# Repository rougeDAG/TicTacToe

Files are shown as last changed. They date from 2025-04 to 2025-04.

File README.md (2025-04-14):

<h1>TicTacToe</h1>

A first year graded project I submitted for my course in Digital System Design (Winter Semester, Vellore Institue of Technology, Chennai). This is a Tic Tac Toe game that uses only digital logic to play the game. PCB Design was done on KiCad , an open source PCB Design software. I simulated the circuit in another open source digital simulator called Digital.exe (which is based on another software called Logisim) by Helmut Neemann which I downloaded from his GitHub repository.
Digital.exe helped me immensely in my project as I cannot have simulated my project without this software for free. Here is his GitHub repository: [github.com/hneemann/Digital](#github.com/hneemann/Digital)


_________________________________________________________________________________________________________________________________________________________________________________________________________________________________________________

Now for KiCad, I used another free and open source software called Freerouting by Andras Fuchs to auto-route my wire connections in KiCad. Here is that GitHub repository: [github.com/freerouting/freerouting](#github.com/freerouting/freerouting)

Again it would've been painstaking to connect all the components pinouts invidivually , thus this software also played a massive role in saving time as I had to submit my project in a short span of time.

 To open the files in KiCad, go to KiCad, click on File->Open Project and then open the file folder thats downloaded and click on "DSD_Project" of the file type "KiCad Project 9.0". Updated versions may come in the future but it still should work the same.

 To open the files in Digital.exe, go to Digital, click on Open and click on "dsd_project_digital.dig".

_________________________________________________________________________________________________________________________________________________________________________________________________________________________________________________

<h1>Sneek Peek into Digital.exe simulation:</h1>






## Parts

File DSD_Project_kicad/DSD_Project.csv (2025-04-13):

Reference | Qty | Value | DNP | Exclude from BOM | Exclude from Board | Footprint | Datasheet | Description | #
button1,button2,button3,button4,button5,button6,button7,button8,button9,D_Clear1,D_Preset1 | 11 | SW_Push |  |  |  |  | ~ | Push button switch, generic, two pins | 1
U1,U6,U8 | 3 | 74LS02 |  |  |  |  | http://www.ti.com/lit/gpn/sn74ls02 | quad 2-input NOR gate | 2
U2,U9,U10,U12,U13,U14 | 6 | 74LS11 |  |  |  |  | http://www.ti.com/lit/gpn/sn74LS11 | Triple 3-input AND | 3
U3,U5,U7 | 3 | 74LS08 |  |  |  |  | http://www.ti.com/lit/gpn/sn74LS08 | Quad And2 | 4
U4,U11 | 2 | 74LS14 |  |  |  |  | http://www.ti.com/lit/gpn/sn74LS14 | Hex inverter schmitt trigger | 5
U15,U16,U17,U18,U19,U20,U21,U22,U23 | 9 | 74LS74 |  |  |  |  | 74xx/74hc_hct74.pdf | Dual D Flip-flop, Set & Reset | 6

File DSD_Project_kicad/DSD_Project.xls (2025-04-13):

Reference | Qty | Value | DNP | Exclude from BOM | Exclude from Board | Footprint | Datasheet | Description | #
button1,button2,button3,button4,button5,button6,button7,button8,button9,D_Clear?,D_Preset? | 11 | SW_Push |  |  |  |  | ~ | Push button switch, generic, two pins | 1
U1,U11,U13,U15,U20,U21,U24,U26,U28 | 9 | 74LS74 |  |  |  |  | 74xx/74hc_hct74.pdf | Dual D Flip-flop, Set & Reset | 2
U2,U18,U27 | 3 | 74LS02 |  |  |  |  | http://www.ti.com/lit/gpn/sn74ls02 | quad 2-input NOR gate | 3
U3,U5,U17 | 3 | 74LS08 |  |  |  |  | http://www.ti.com/lit/gpn/sn74LS08 | Quad And2 | 4
U4,U8,U9,U19,U22,U25 | 6 | 74LS11 |  |  |  |  | http://www.ti.com/lit/gpn/sn74LS11 | Triple 3-input AND | 5
U6,U23 | 2 | 74LS14 |  |  |  |  | http://www.ti.com/lit/gpn/sn74LS14 | Hex inverter schmitt trigger | 6

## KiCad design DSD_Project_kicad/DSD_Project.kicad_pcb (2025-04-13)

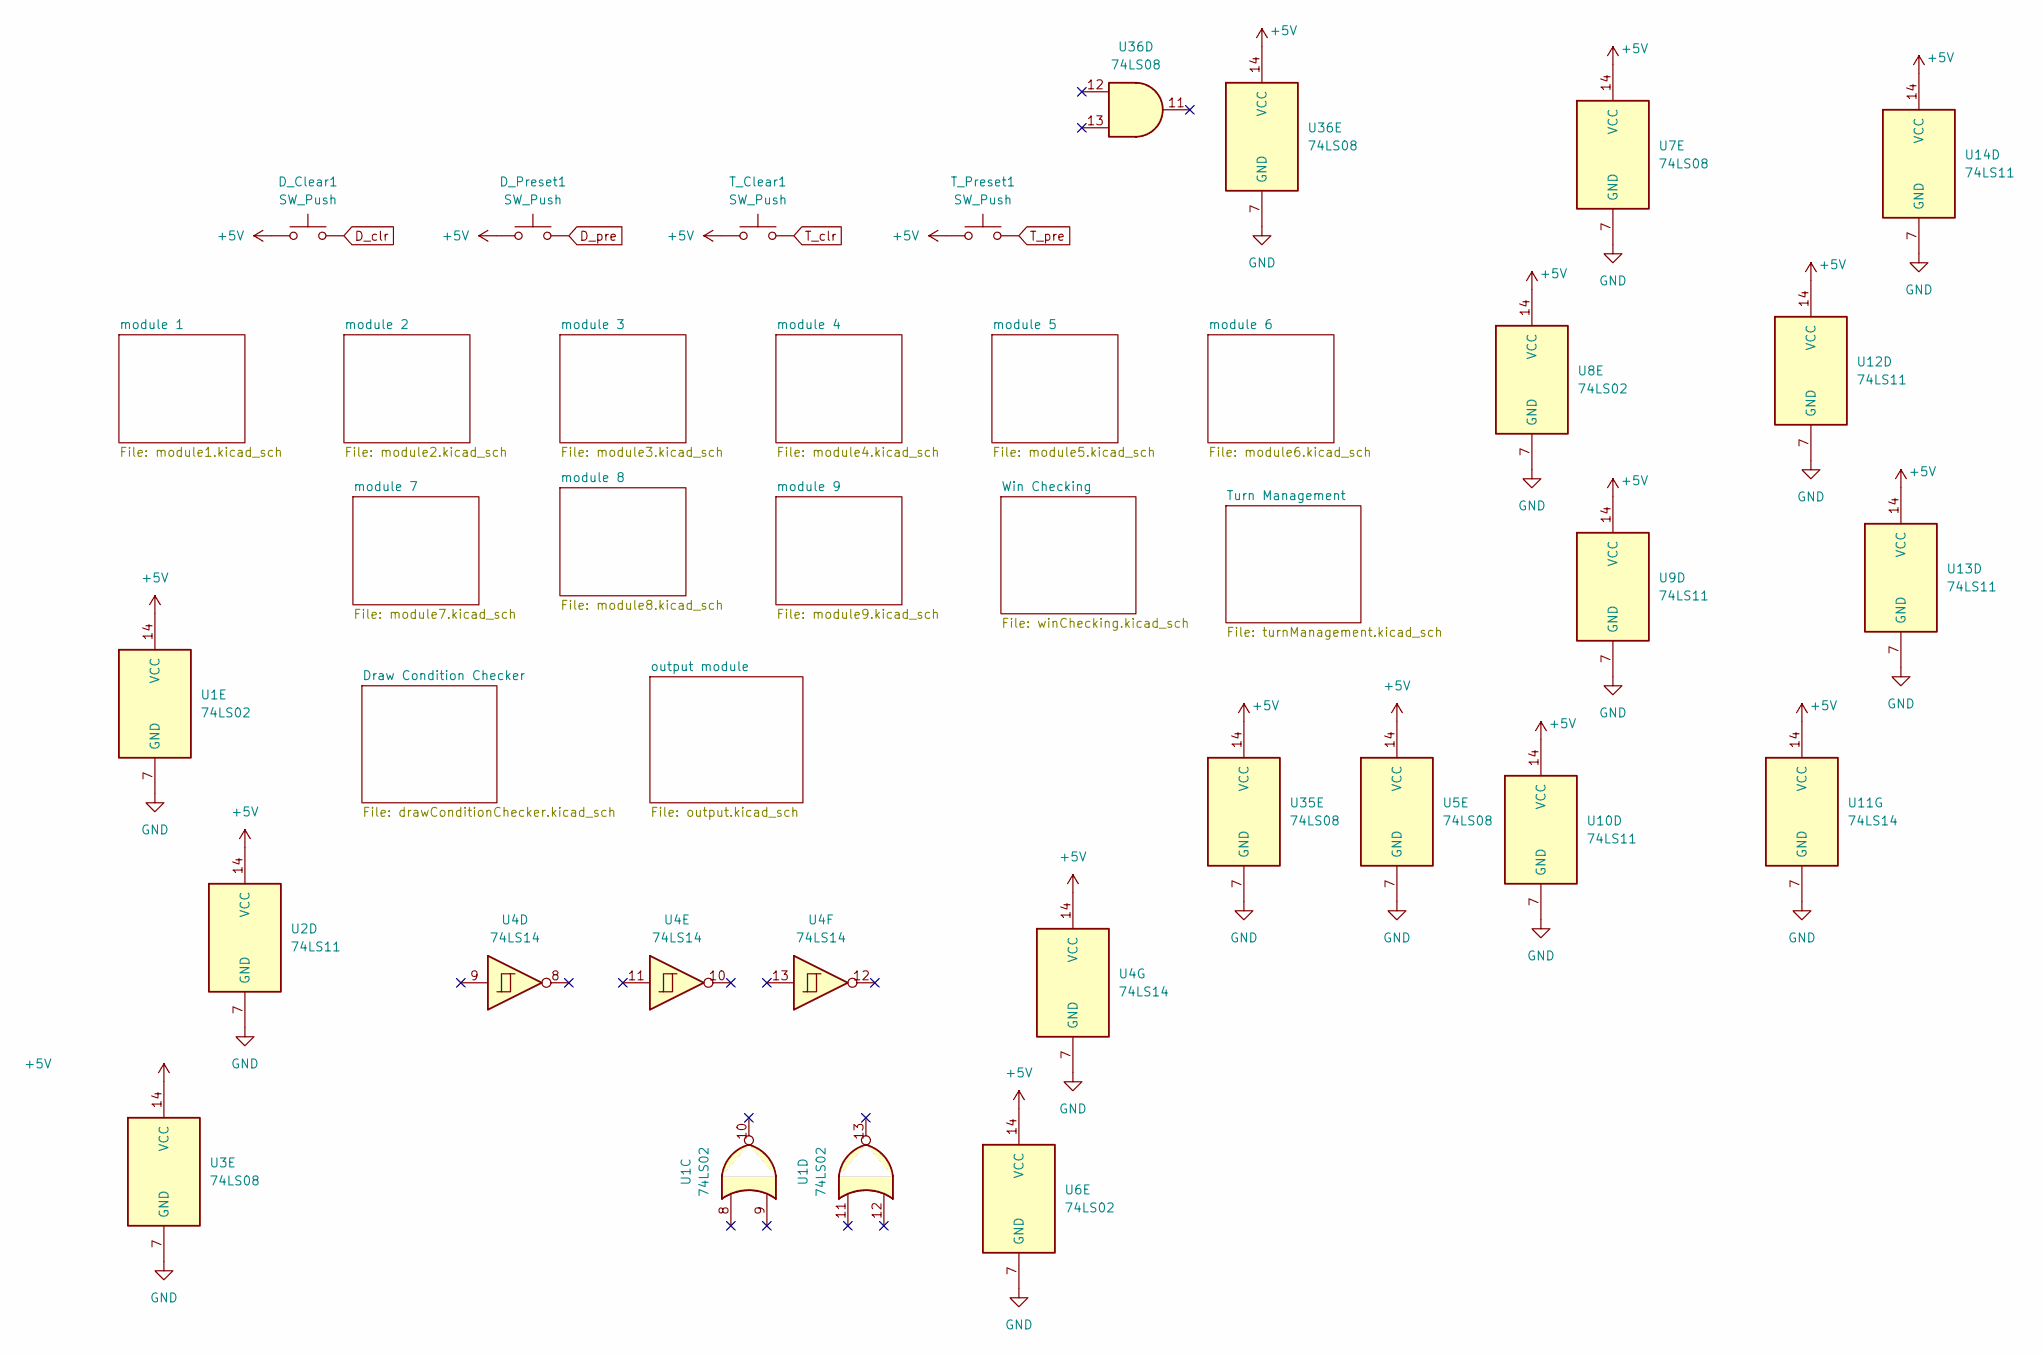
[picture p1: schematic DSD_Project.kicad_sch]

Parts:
D_Clear1: SW_Push; SW_SPDT_PCM12
D_Preset1: SW_Push; SW_SPDT_PCM12
T_Clear1: SW_Push; SW_SPDT_PCM12
T_Preset1: SW_Push; SW_SPDT_PCM12
U1, U6, U8: 74LS02; DIP-14_W7.62mm
U2, U9, U10, U12, U13, U14: 74LS11; DIP-14_W7.62mm
U3, U5, U7, U35, U36: 74LS08; DIP-14_W7.62mm
U4, U11: 74LS14; DIP-14_W7.62mm

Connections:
+5V: D_Clear1.1, D_Preset1.1, T_Clear1.1, T_Preset1.1, U1.14 (VCC), U2.14 (VCC), U3.14 (VCC), U4.14 (VCC), U5.14 (VCC), U6.14 (VCC), U7.14 (VCC), U8.14 (VCC), U9.14 (VCC), U10.14 (VCC), U11.14 (VCC), U12.14 (VCC), U13.14 (VCC), U14.14 (VCC), U35.14 (VCC), U36.14 (VCC); also elsewhere on the board
D_clr: D_Clear1.2; also elsewhere on the board
D_pre: D_Preset1.2; also elsewhere on the board
GND: U1.7 (GND), U2.7 (GND), U3.7 (GND), U4.7 (GND), U5.7 (GND), U6.7 (GND), U7.7 (GND), U8.7 (GND), U9.7 (GND), U10.7 (GND), U11.7 (GND), U12.7 (GND), U13.7 (GND), U14.7 (GND), U35.7 (GND), U36.7 (GND); also elsewhere on the board
T_clr: T_Clear1.2; also elsewhere on the board
T_pre: T_Preset1.2; also elsewhere on the board

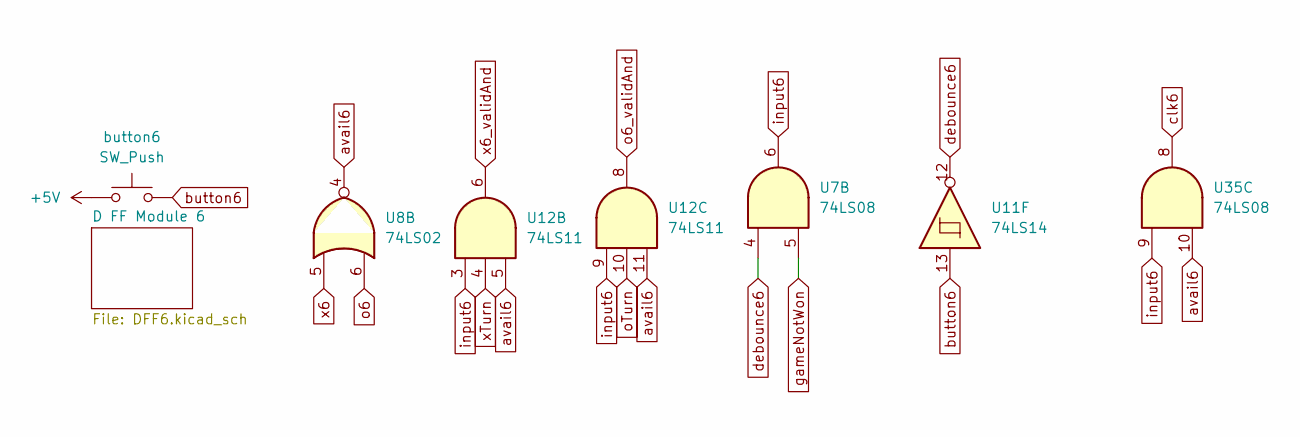
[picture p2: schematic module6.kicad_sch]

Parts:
U7, U35: 74LS08; DIP-14_W7.62mm
U8: 74LS02; DIP-14_W7.62mm
U11: 74LS14; DIP-14_W7.62mm
U12: 74LS11; DIP-14_W7.62mm
button6: SW_Push; SW_PUSH_6mm

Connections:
+5V: button6.1; also elsewhere on the board
avail6: U8.4, U12.5, U12.11, U35.10; also elsewhere on the board
button6: U11.13, button6.2
clk6: U35.8; also elsewhere on the board
debounce6: U7.4, U11.12
gameNotWon: U7.5; also elsewhere on the board
input6: U7.6, U12.3, U12.9, U35.9
o6: U8.6; also elsewhere on the board
o6_validAnd: U12.8; also elsewhere on the board
oTurn: U12.10; also elsewhere on the board
x6: U8.5; also elsewhere on the board
x6_validAnd: U12.6; also elsewhere on the board
xTurn: U12.4; also elsewhere on the board

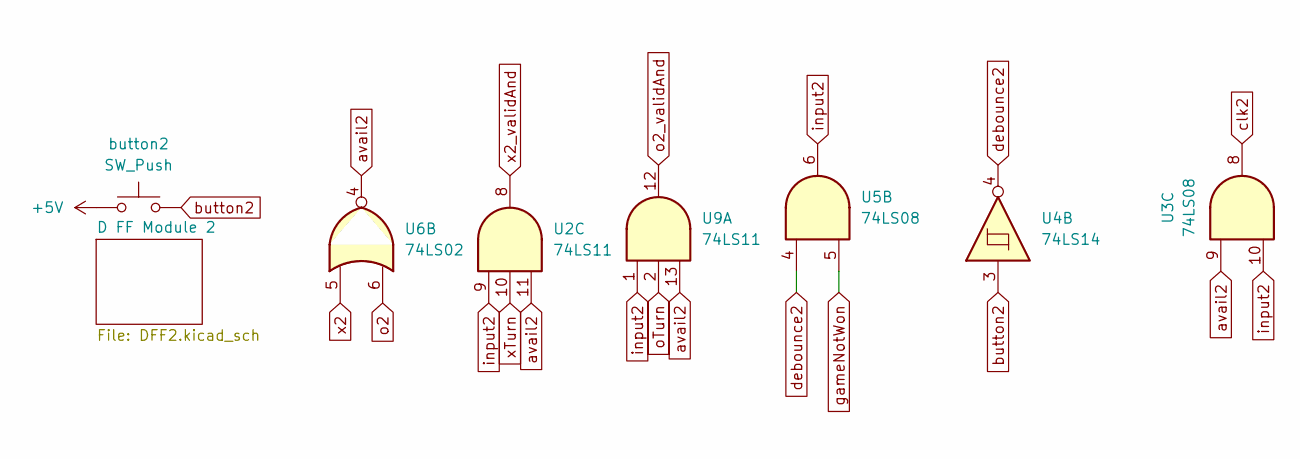
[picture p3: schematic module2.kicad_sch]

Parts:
U2, U9: 74LS11; DIP-14_W7.62mm
U3, U5: 74LS08; DIP-14_W7.62mm
U4: 74LS14; DIP-14_W7.62mm
U6: 74LS02; DIP-14_W7.62mm
button2: SW_Push; SW_PUSH_6mm

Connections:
+5V: button2.1; also elsewhere on the board
avail2: U2.11, U3.9, U6.4, U9.13; also elsewhere on the board
button2: U4.3, button2.2
clk2: U3.8; also elsewhere on the board
debounce2: U4.4, U5.4
gameNotWon: U5.5; also elsewhere on the board
input2: U2.9, U3.10, U5.6, U9.1
o2: U6.6; also elsewhere on the board
o2_validAnd: U9.12; also elsewhere on the board
oTurn: U9.2; also elsewhere on the board
x2: U6.5; also elsewhere on the board
x2_validAnd: U2.8; also elsewhere on the board
xTurn: U2.10; also elsewhere on the board

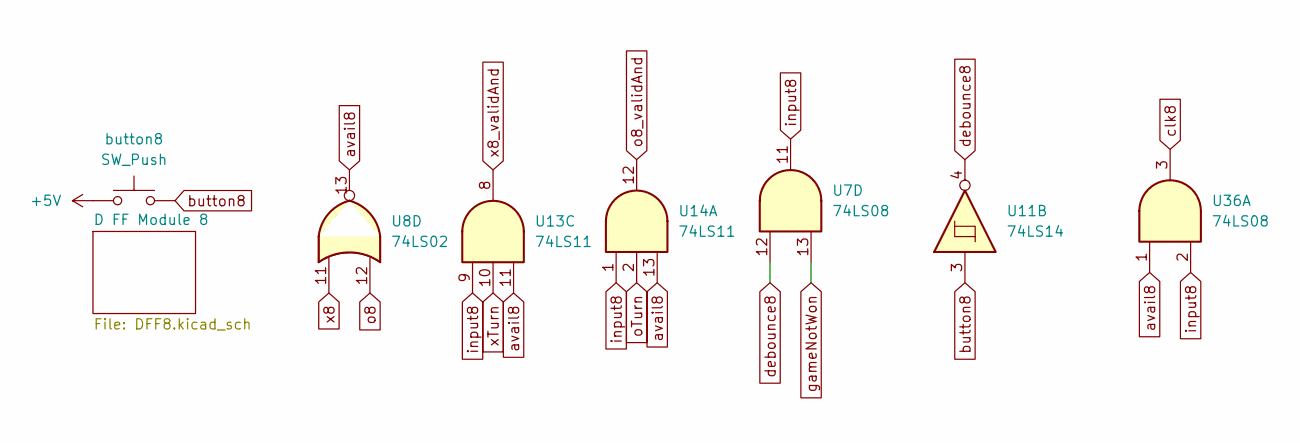
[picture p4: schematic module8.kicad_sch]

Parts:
U7, U36: 74LS08; DIP-14_W7.62mm
U8: 74LS02; DIP-14_W7.62mm
U11: 74LS14; DIP-14_W7.62mm
U13, U14: 74LS11; DIP-14_W7.62mm
button8: SW_Push; SW_PUSH_6mm

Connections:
+5V: button8.1; also elsewhere on the board
avail8: U8.13, U13.11, U14.13, U36.1; also elsewhere on the board
button8: U11.3, button8.2
clk8: U36.3; also elsewhere on the board
debounce8: U7.12, U11.4
gameNotWon: U7.13; also elsewhere on the board
input8: U7.11, U13.9, U14.1, U36.2
o8: U8.12; also elsewhere on the board
o8_validAnd: U14.12; also elsewhere on the board
oTurn: U14.2; also elsewhere on the board
x8: U8.11; also elsewhere on the board
x8_validAnd: U13.8; also elsewhere on the board
xTurn: U13.10; also elsewhere on the board

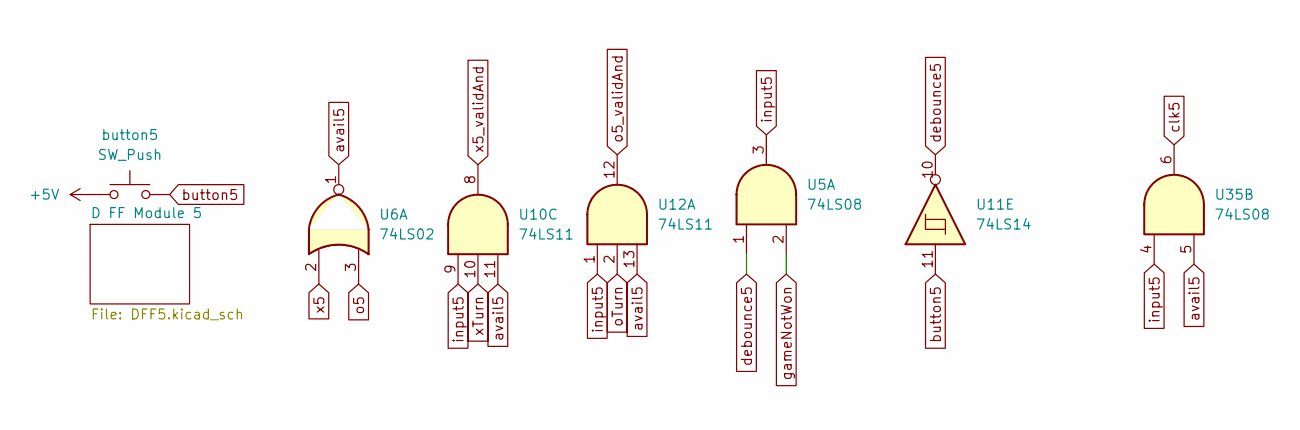
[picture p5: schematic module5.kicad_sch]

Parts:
U5, U35: 74LS08; DIP-14_W7.62mm
U6: 74LS02; DIP-14_W7.62mm
U10, U12: 74LS11; DIP-14_W7.62mm
U11: 74LS14; DIP-14_W7.62mm
button5: SW_Push; SW_PUSH_6mm

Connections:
+5V: button5.1; also elsewhere on the board
avail5: U6.1, U10.11, U12.13, U35.5; also elsewhere on the board
button5: U11.11, button5.2
clk5: U35.6; also elsewhere on the board
debounce5: U5.1, U11.10
gameNotWon: U5.2; also elsewhere on the board
input5: U5.3, U10.9, U12.1, U35.4
o5: U6.3; also elsewhere on the board
o5_validAnd: U12.12; also elsewhere on the board
oTurn: U12.2; also elsewhere on the board
x5: U6.2; also elsewhere on the board
x5_validAnd: U10.8; also elsewhere on the board
xTurn: U10.10; also elsewhere on the board

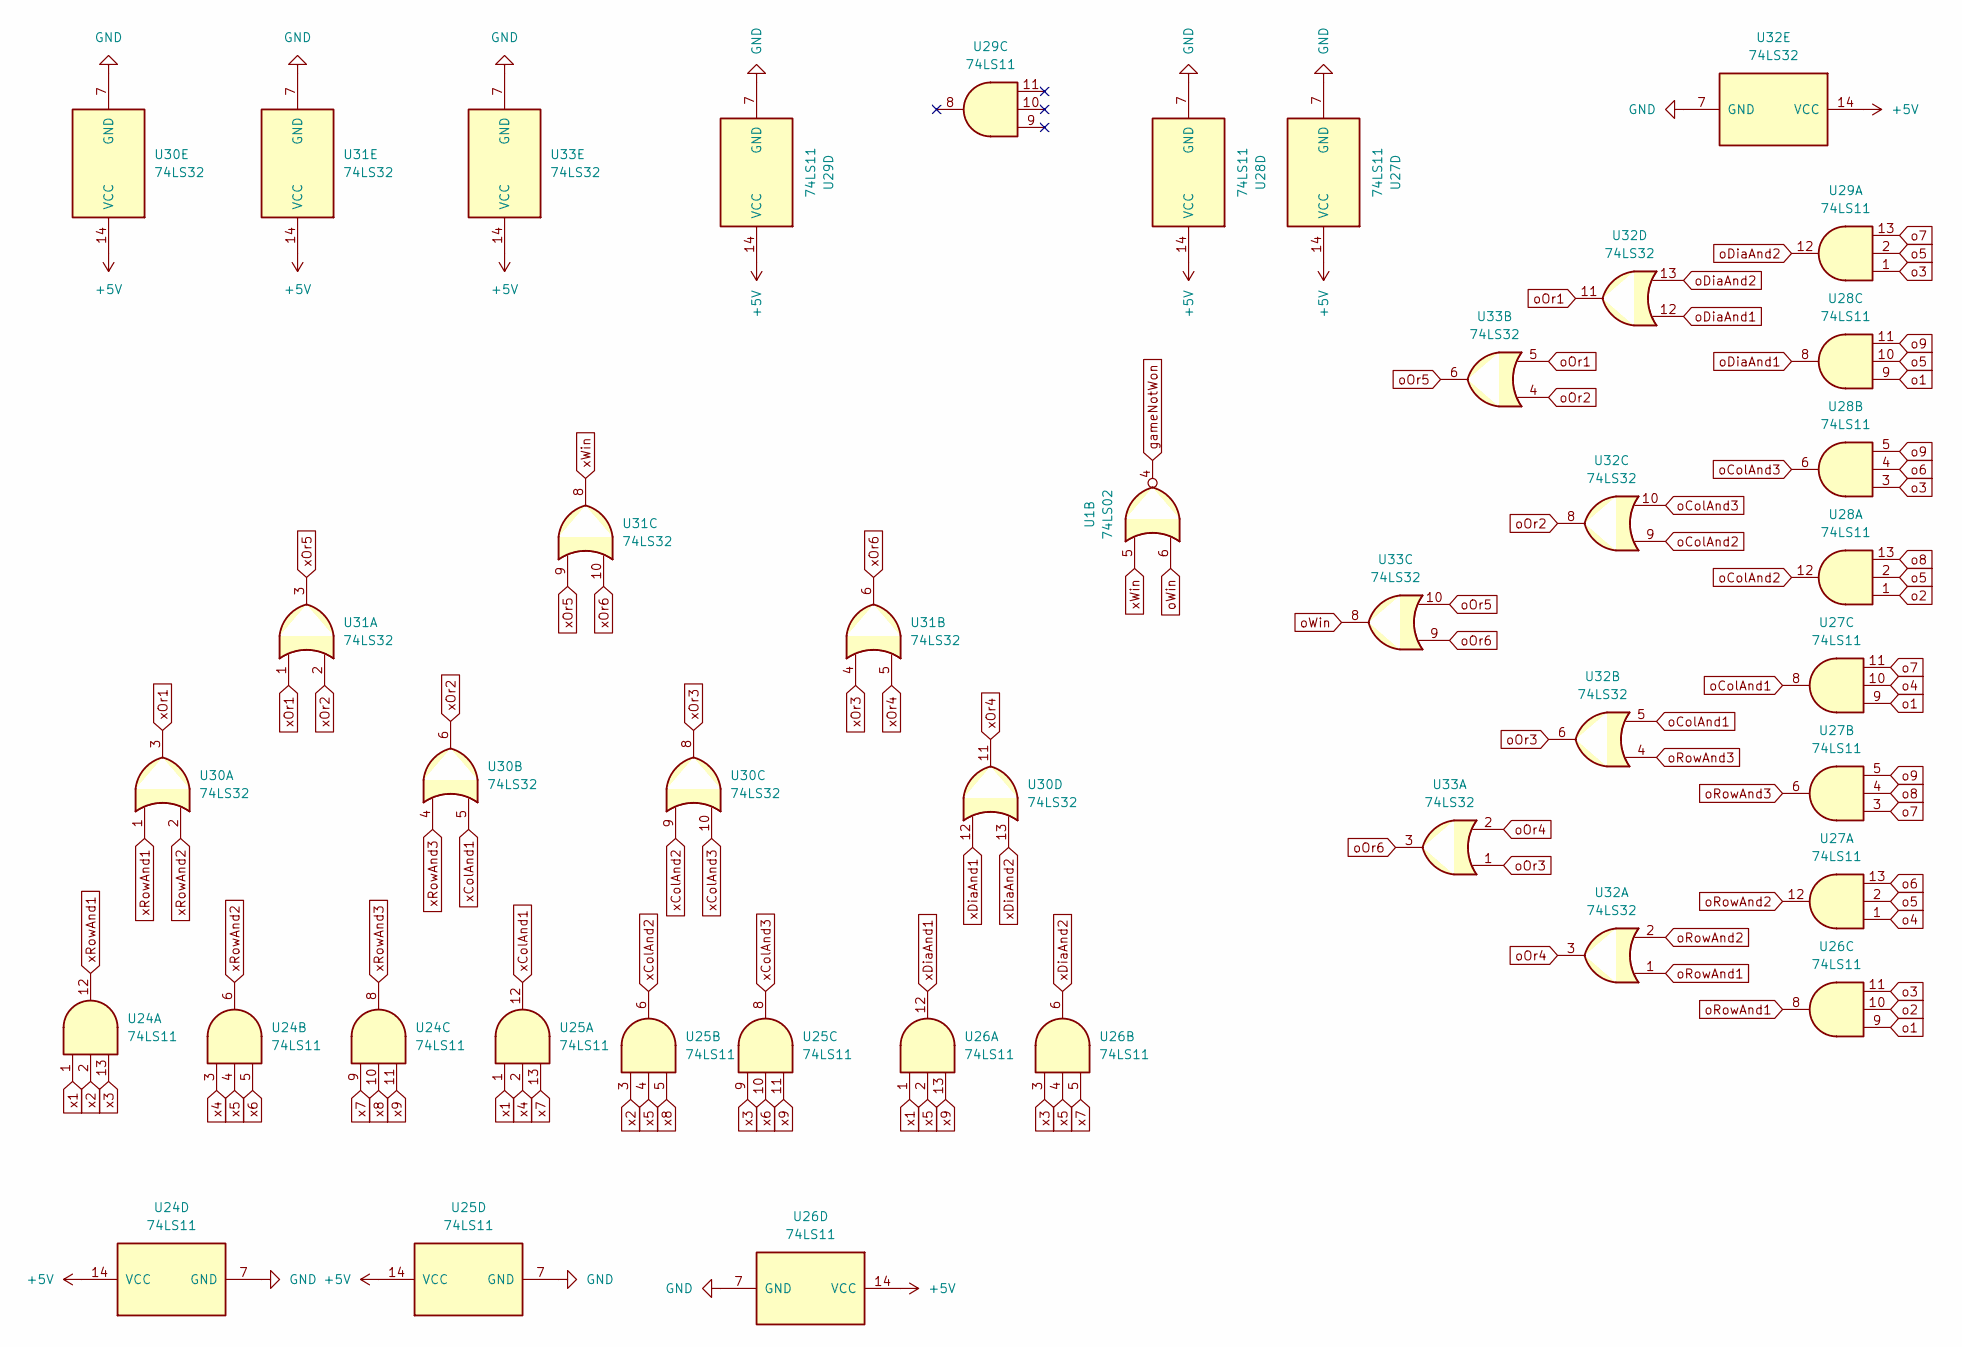
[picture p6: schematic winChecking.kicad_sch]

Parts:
U1: 74LS02; DIP-14_W7.62mm
U24, U25, U26, U27, U28, U29: 74LS11; DIP-14_W7.62mm
U30, U31, U32, U33: 74LS32; DIP-14_W7.62mm

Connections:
+5V: U24.14 (VCC), U25.14 (VCC), U26.14 (VCC), U27.14 (VCC), U28.14 (VCC), U29.14 (VCC), U30.14 (VCC), U31.14 (VCC), U32.14 (VCC), U33.14 (VCC); also elsewhere on the board
GND: U24.7 (GND), U25.7 (GND), U26.7 (GND), U27.7 (GND), U28.7 (GND), U29.7 (GND), U30.7 (GND), U31.7 (GND), U32.7 (GND), U33.7 (GND); also elsewhere on the board
gameNotWon: U1.4; also elsewhere on the board
o1: U26.9, U27.9, U28.9; also elsewhere on the board
o2: U26.10, U28.1; also elsewhere on the board
o3: U26.11, U28.3, U29.1; also elsewhere on the board
o4: U27.1, U27.10; also elsewhere on the board
o5: U27.2, U28.2, U28.10, U29.2; also elsewhere on the board
o6: U27.13, U28.4; also elsewhere on the board
o7: U27.3, U27.11, U29.13; also elsewhere on the board
o8: U27.4, U28.13; also elsewhere on the board
o9: U27.5, U28.5, U28.11; also elsewhere on the board
oColAnd1: U27.8, U32.5
oColAnd2: U28.12, U32.9
oColAnd3: U28.6, U32.10
oDiaAnd1: U28.8, U32.12
oDiaAnd2: U29.12, U32.13
oOr1: U32.11, U33.5
oOr2: U32.8, U33.4
oOr3: U32.6, U33.1
oOr4: U32.3, U33.2
oOr5: U33.6, U33.10
oOr6: U33.3, U33.9
oRowAnd1: U26.8, U32.1
oRowAnd2: U27.12, U32.2
oRowAnd3: U27.6, U32.4
oWin: U1.6, U33.8; also elsewhere on the board
x1: U24.1, U25.1, U26.1; also elsewhere on the board
x2: U24.2, U25.3; also elsewhere on the board
x3: U24.13, U25.9, U26.3; also elsewhere on the board
x4: U24.3, U25.2; also elsewhere on the board
x5: U24.4, U25.4, U26.2, U26.4; also elsewhere on the board
x6: U24.5, U25.10; also elsewhere on the board
x7: U24.9, U25.13, U26.5; also elsewhere on the board
x8: U24.10, U25.5; also elsewhere on the board
x9: U24.11, U25.11, U26.13; also elsewhere on the board
xColAnd1: U25.12, U30.5
xColAnd2: U25.6, U30.9
xColAnd3: U25.8, U30.10
xDiaAnd1: U26.12, U30.12
xDiaAnd2: U26.6, U30.13
xOr1: U30.3, U31.1
xOr2: U30.6, U31.2
xOr3: U30.8, U31.4
xOr4: U30.11, U31.5
xOr5: U31.3, U31.9
xOr6: U31.6, U31.10
xRowAnd1: U24.12, U30.1
xRowAnd2: U24.6, U30.2
xRowAnd3: U24.8, U30.4
xWin: U1.5, U31.8; also elsewhere on the board

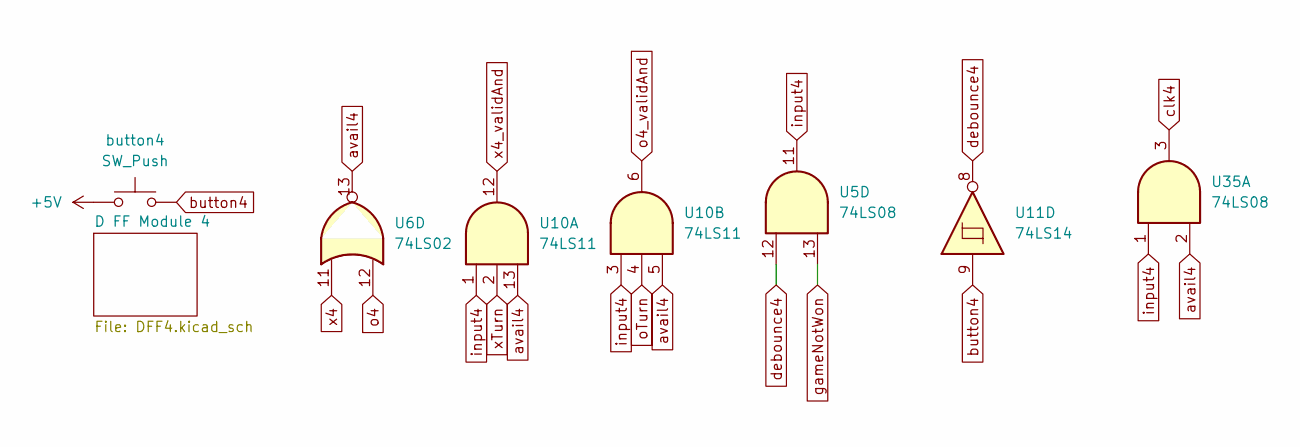
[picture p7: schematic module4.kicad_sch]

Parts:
U5, U35: 74LS08; DIP-14_W7.62mm
U6: 74LS02; DIP-14_W7.62mm
U10: 74LS11; DIP-14_W7.62mm
U11: 74LS14; DIP-14_W7.62mm
button4: SW_Push; SW_PUSH_6mm

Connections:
+5V: button4.1; also elsewhere on the board
avail4: U6.13, U10.5, U10.13, U35.2; also elsewhere on the board
button4: U11.9, button4.2
clk4: U35.3; also elsewhere on the board
debounce4: U5.12, U11.8
gameNotWon: U5.13; also elsewhere on the board
input4: U5.11, U10.1, U10.3, U35.1
o4: U6.12; also elsewhere on the board
o4_validAnd: U10.6; also elsewhere on the board
oTurn: U10.4; also elsewhere on the board
x4: U6.11; also elsewhere on the board
x4_validAnd: U10.12; also elsewhere on the board
xTurn: U10.2; also elsewhere on the board

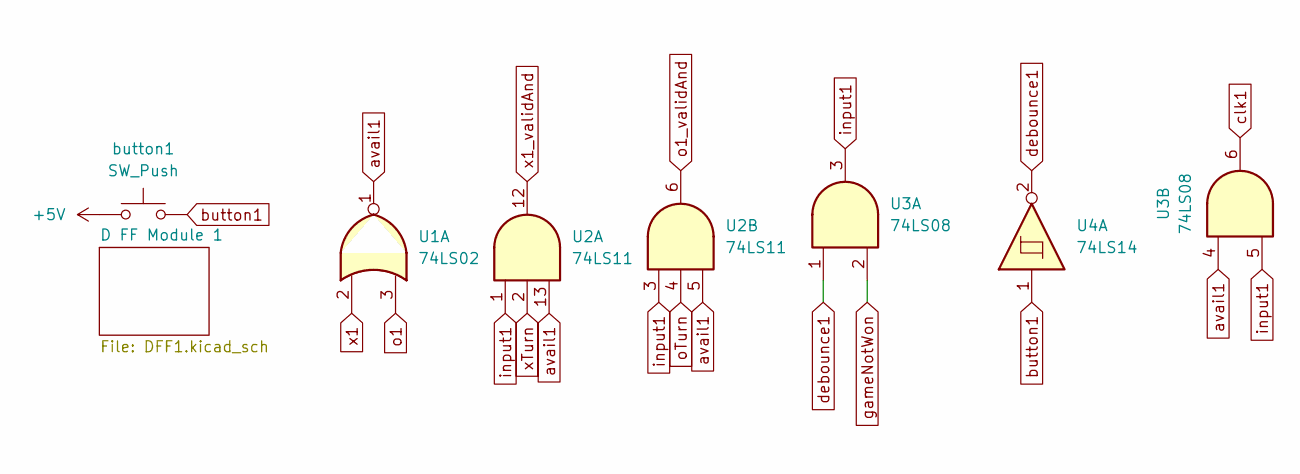
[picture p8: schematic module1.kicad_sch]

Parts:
U1: 74LS02; DIP-14_W7.62mm
U2: 74LS11; DIP-14_W7.62mm
U3: 74LS08; DIP-14_W7.62mm
U4: 74LS14; DIP-14_W7.62mm
button1: SW_Push; SW_PUSH_6mm

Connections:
+5V: button1.1; also elsewhere on the board
avail1: U1.1, U2.5, U2.13, U3.4; also elsewhere on the board
button1: U4.1, button1.2
clk1: U3.6; also elsewhere on the board
debounce1: U3.1, U4.2
gameNotWon: U3.2; also elsewhere on the board
input1: U2.1, U2.3, U3.3, U3.5
o1: U1.3; also elsewhere on the board
o1_validAnd: U2.6; also elsewhere on the board
oTurn: U2.4; also elsewhere on the board
x1: U1.2; also elsewhere on the board
x1_validAnd: U2.12; also elsewhere on the board
xTurn: U2.2; also elsewhere on the board

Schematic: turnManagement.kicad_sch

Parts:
U31, U33, U37, U38: 74LS32; DIP-14_W7.62mm
U34: 74LS76; DIP-16_W7.62mm

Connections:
+5V: U34.4 (J), U34.5 (VCC), U34.16 (K), U37.14 (VCC), U38.14 (VCC); also elsewhere on the board
GND: U34.13 (GND), U37.7 (GND), U38.7 (GND); also elsewhere on the board
T_clr: U34.3 (~R); also elsewhere on the board
T_pre: U34.2 (~S); also elsewhere on the board
clk1: U31.12; also elsewhere on the board
clk2: U31.13; also elsewhere on the board
clk3: U33.12; also elsewhere on the board
clk4: U33.13; also elsewhere on the board
clk5: U37.1; also elsewhere on the board
clk6: U37.2; also elsewhere on the board
clk7: U37.4; also elsewhere on the board
clk8: U37.5; also elsewhere on the board
clk9: U37.10; also elsewhere on the board
clkOr1: U31.11, U38.4
clkOr2: U33.11, U37.12
clkOr3: U37.3, U37.13
clkOr4: U37.6, U37.9
clkOr5: U37.11, U38.1
clkOr6: U37.8, U38.2
clkOr7: U38.3, U38.5
oTurn: U34.14 (~Q); also elsewhere on the board
tclk: U34.1 (C), U38.6
xTurn: U34.15 (Q); also elsewhere on the board

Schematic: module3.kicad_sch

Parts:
U3, U5: 74LS08; DIP-14_W7.62mm
U4: 74LS14; DIP-14_W7.62mm
U6: 74LS02; DIP-14_W7.62mm
U9: 74LS11; DIP-14_W7.62mm
button3: SW_Push; SW_PUSH_6mm

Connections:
+5V: button3.1; also elsewhere on the board
avail3: U3.12, U6.10, U9.5, U9.11; also elsewhere on the board
button3: U4.5, button3.2
clk3: U3.11; also elsewhere on the board
debounce3: U4.6, U5.9
gameNotWon: U5.10; also elsewhere on the board
input3: U3.13, U5.8, U9.3, U9.9
o3: U6.9; also elsewhere on the board
o3_validAnd: U9.8; also elsewhere on the board
oTurn: U9.10; also elsewhere on the board
x3: U6.8; also elsewhere on the board
x3_validAnd: U9.6; also elsewhere on the board
xTurn: U9.4; also elsewhere on the board

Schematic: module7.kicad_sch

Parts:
U7, U35: 74LS08; DIP-14_W7.62mm
U8: 74LS02; DIP-14_W7.62mm
U11: 74LS14; DIP-14_W7.62mm
U13: 74LS11; DIP-14_W7.62mm
button7: SW_Push; SW_PUSH_6mm

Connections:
+5V: button7.1; also elsewhere on the board
avail7: U8.10, U13.5, U13.13, U35.13; also elsewhere on the board
button7: U11.1, button7.2
clk7: U35.11; also elsewhere on the board
debounce7: U7.9, U11.2
gameNotWon: U7.10; also elsewhere on the board
input7: U7.8, U13.1, U13.3, U35.12
o7: U8.9; also elsewhere on the board
o7_validAnd: U13.6; also elsewhere on the board
oTurn: U13.4; also elsewhere on the board
x7: U8.8; also elsewhere on the board
x7_validAnd: U13.12; also elsewhere on the board
xTurn: U13.2; also elsewhere on the board

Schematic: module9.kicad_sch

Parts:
U7, U36: 74LS08; DIP-14_W7.62mm
U8: 74LS02; DIP-14_W7.62mm
U11: 74LS14; DIP-14_W7.62mm
U14: 74LS11; DIP-14_W7.62mm
button9: SW_Push; SW_PUSH_6mm

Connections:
+5V: button9.1; also elsewhere on the board
avail9: U8.1, U14.5, U14.11, U36.5; also elsewhere on the board
button9: U11.5, button9.2
clk9: U36.6; also elsewhere on the board
debounce9: U7.1, U11.6
gameNotWon: U7.2; also elsewhere on the board
input9: U7.3, U14.3, U14.9, U36.4
o9: U8.3; also elsewhere on the board
o9_validAnd: U14.8; also elsewhere on the board
oTurn: U14.10; also elsewhere on the board
x9: U8.2; also elsewhere on the board
x9_validAnd: U14.6; also elsewhere on the board
xTurn: U14.4; also elsewhere on the board

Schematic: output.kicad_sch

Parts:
BT1: 12V; TerminalBlock_Phoenix_MKDS-3-2-5.08_1x02_P5.08mm_Horizontal
DRAW1: LED; LED_D3.0mm
O_WON1: LED; LED_D3.0mm
Q1, Q2, Q3: NPN; TO-92_Inline
R1, R3, R5: 6800; R_Axial_DIN0309_L9.0mm_D3.2mm_P12.70mm_Horizontal
R2, R4, R6: 150; R_Axial_DIN0207_L6.3mm_D2.5mm_P7.62mm_Horizontal
U40: XL1509-5.0; SOIC-8_3.9x4.9mm_P1.27mm
X_WON1: LED; LED_D3.0mm
buckEn1: SW_Push; SW_SPDT_PCM12

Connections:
+5V: R2.2, R4.2, R6.2, U40.2 (OUT), U40.3 (FB), buckEn1.2; also elsewhere on the board
GND: BT1.2 (-), Q1.3 (E), Q2.3 (E), Q3.3 (E), U40.5 (GND), U40.6 (GND), U40.7 (GND), U40.8 (GND); also elsewhere on the board
unnamed: BT1.1 (+), U40.1 (VIN)
unnamed: DRAW1.2 (A), R6.1
unnamed: DRAW1.1 (K), Q3.1 (C)
unnamed: O_WON1.2 (A), R4.1
unnamed: O_WON1.1 (K), Q2.1 (C)
unnamed: Q1.2 (B), R1.2
unnamed: Q1.1 (C), X_WON1.1 (K)
unnamed: Q2.2 (B), R3.2
unnamed: Q3.2 (B), R5.2
unnamed: U40.4 (~EN), buckEn1.1
unnamed: R2.1, X_WON1.2 (A)
draw: R5.1; also elsewhere on the board
oWin: R3.1; also elsewhere on the board
xWin: R1.1; also elsewhere on the board

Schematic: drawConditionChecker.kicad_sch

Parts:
U29: 74LS11; DIP-14_W7.62mm
U36: 74LS08; DIP-14_W7.62mm
U39: 74LS27; DIP-14_W7.62mm

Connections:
+5V: U39.14 (VCC); also elsewhere on the board
GND: U39.7 (GND); also elsewhere on the board
avail1: U39.1; also elsewhere on the board
avail2: U39.2; also elsewhere on the board
avail3: U39.13; also elsewhere on the board
avail4: U39.3; also elsewhere on the board
avail5: U39.4; also elsewhere on the board
avail6: U39.5; also elsewhere on the board
avail7: U39.9; also elsewhere on the board
avail8: U39.10; also elsewhere on the board
avail9: U39.11; also elsewhere on the board
draw: U36.8; also elsewhere on the board
drawAnd: U29.6, U36.9
gameNotWon: U36.10; also elsewhere on the board
nor1: U29.5, U39.12
nor2: U29.4, U39.6
nor3: U29.3, U39.8

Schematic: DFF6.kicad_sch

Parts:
U20: 74LS74; DIP-14_W7.62mm

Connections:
+5V: U20.2 (D), U20.12 (D), U20.14 (VCC); also elsewhere on the board
D_clr: U20.1 (~R), U20.13 (~R); also elsewhere on the board
D_pre: U20.4 (~S), U20.10 (~S); also elsewhere on the board
GND: U20.7 (GND); also elsewhere on the board
o6: U20.9 (Q); also elsewhere on the board
o6_validAnd: U20.11 (C); also elsewhere on the board
x6: U20.5 (Q); also elsewhere on the board
x6_validAnd: U20.3 (C); also elsewhere on the board

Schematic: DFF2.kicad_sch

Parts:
U16: 74LS74; DIP-14_W7.62mm

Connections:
+5V: U16.2 (D), U16.12 (D), U16.14 (VCC); also elsewhere on the board
D_clr: U16.1 (~R), U16.13 (~R); also elsewhere on the board
D_pre: U16.4 (~S), U16.10 (~S); also elsewhere on the board
GND: U16.7 (GND); also elsewhere on the board
o2: U16.9 (Q); also elsewhere on the board
o2_validAnd: U16.11 (C); also elsewhere on the board
x2: U16.5 (Q); also elsewhere on the board
x2_validAnd: U16.3 (C); also elsewhere on the board

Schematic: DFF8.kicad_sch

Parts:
U22: 74LS74; DIP-14_W7.62mm

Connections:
+5V: U22.2 (D), U22.12 (D), U22.14 (VCC); also elsewhere on the board
D_clr: U22.1 (~R), U22.13 (~R); also elsewhere on the board
D_pre: U22.4 (~S), U22.10 (~S); also elsewhere on the board
GND: U22.7 (GND); also elsewhere on the board
o8: U22.9 (Q); also elsewhere on the board
o8_validAnd: U22.11 (C); also elsewhere on the board
x8: U22.5 (Q); also elsewhere on the board
x8_validAnd: U22.3 (C); also elsewhere on the board

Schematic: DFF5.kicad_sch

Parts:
U19: 74LS74; DIP-14_W7.62mm

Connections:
+5V: U19.2 (D), U19.12 (D), U19.14 (VCC); also elsewhere on the board
D_clr: U19.1 (~R), U19.13 (~R); also elsewhere on the board
D_pre: U19.4 (~S), U19.10 (~S); also elsewhere on the board
GND: U19.7 (GND); also elsewhere on the board
o5: U19.9 (Q); also elsewhere on the board
o5_validAnd: U19.11 (C); also elsewhere on the board
x5: U19.5 (Q); also elsewhere on the board
x5_validAnd: U19.3 (C); also elsewhere on the board

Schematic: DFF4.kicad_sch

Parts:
U18: 74LS74; DIP-14_W7.62mm

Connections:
+5V: U18.2 (D), U18.12 (D), U18.14 (VCC); also elsewhere on the board
D_clr: U18.1 (~R), U18.13 (~R); also elsewhere on the board
D_pre: U18.4 (~S), U18.10 (~S); also elsewhere on the board
GND: U18.7 (GND); also elsewhere on the board
o4: U18.9 (Q); also elsewhere on the board
o4_validAnd: U18.11 (C); also elsewhere on the board
x4: U18.5 (Q); also elsewhere on the board
x4_validAnd: U18.3 (C); also elsewhere on the board

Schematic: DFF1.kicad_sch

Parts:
U15: 74LS74; DIP-14_W7.62mm

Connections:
+5V: U15.2 (D), U15.12 (D), U15.14 (VCC); also elsewhere on the board
D_clr: U15.1 (~R), U15.13 (~R); also elsewhere on the board
D_pre: U15.4 (~S), U15.10 (~S); also elsewhere on the board
GND: U15.7 (GND); also elsewhere on the board
o1: U15.9 (Q); also elsewhere on the board
o1_validAnd: U15.11 (C); also elsewhere on the board
x1: U15.5 (Q); also elsewhere on the board
x1_validAnd: U15.3 (C); also elsewhere on the board

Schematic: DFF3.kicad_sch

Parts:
U17: 74LS74; DIP-14_W7.62mm

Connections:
+5V: U17.2 (D), U17.12 (D), U17.14 (VCC); also elsewhere on the board
D_clr: U17.1 (~R), U17.13 (~R); also elsewhere on the board
D_pre: U17.4 (~S), U17.10 (~S); also elsewhere on the board
GND: U17.7 (GND); also elsewhere on the board
o3: U17.9 (Q); also elsewhere on the board
o3_validAnd: U17.11 (C); also elsewhere on the board
x3: U17.5 (Q); also elsewhere on the board
x3_validAnd: U17.3 (C); also elsewhere on the board

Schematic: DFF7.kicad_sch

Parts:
U21: 74LS74; DIP-14_W7.62mm

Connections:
+5V: U21.2 (D), U21.12 (D), U21.14 (VCC); also elsewhere on the board
D_clr: U21.1 (~R), U21.13 (~R); also elsewhere on the board
D_pre: U21.4 (~S), U21.10 (~S); also elsewhere on the board
GND: U21.7 (GND); also elsewhere on the board
o7: U21.9 (Q); also elsewhere on the board
o7_validAnd: U21.11 (C); also elsewhere on the board
x7: U21.5 (Q); also elsewhere on the board
x7_validAnd: U21.3 (C); also elsewhere on the board

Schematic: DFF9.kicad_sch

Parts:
U23: 74LS74; DIP-14_W7.62mm

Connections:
+5V: U23.2 (D), U23.12 (D), U23.14 (VCC); also elsewhere on the board
D_clr: U23.1 (~R), U23.13 (~R); also elsewhere on the board
D_pre: U23.4 (~S), U23.10 (~S); also elsewhere on the board
GND: U23.7 (GND); also elsewhere on the board
o9: U23.9 (Q); also elsewhere on the board
o9_validAnd: U23.11 (C); also elsewhere on the board
x9: U23.5 (Q); also elsewhere on the board
x9_validAnd: U23.3 (C); also elsewhere on the board

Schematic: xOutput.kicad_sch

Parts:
Q4, Q5, Q6, Q7, Q8, Q9, Q10, Q11, Q12: NPN; TO-92_Inline
R7, R9, R11, R13, R15, R17, R19, R21, R23: 6800; R_Axial_DIN0309_L9.0mm_D3.2mm_P12.70mm_Horizontal
R8, R10, R12, R14, R16, R18, R20, R22, R24: 150; R_Axial_DIN0207_L6.3mm_D2.5mm_P7.62mm_Horizontal
x1, x2, x3, x4, x5, x6, x7, x8, x9: LED; LED_D3.0mm

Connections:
+5V: R8.2, R10.2, R12.2, R14.2, R16.2, R18.2, R20.2, R22.2, R24.2; also elsewhere on the board
GND: Q4.3 (E), Q5.3 (E), Q6.3 (E), Q7.3 (E), Q8.3 (E), Q9.3 (E), Q10.3 (E), Q11.3 (E), Q12.3 (E); also elsewhere on the board
unnamed: Q4.2 (B), R7.2
unnamed: Q4.1 (C), x1.1 (K)
unnamed: Q5.2 (B), R9.2
unnamed: Q5.1 (C), x2.1 (K)
unnamed: Q6.2 (B), R11.2
unnamed: Q6.1 (C), x3.1 (K)
unnamed: Q7.2 (B), R13.2
unnamed: Q7.1 (C), x4.1 (K)
unnamed: Q8.2 (B), R15.2
unnamed: Q8.1 (C), x5.1 (K)
unnamed: Q9.2 (B), R17.2
unnamed: Q9.1 (C), x6.1 (K)
unnamed: Q10.2 (B), R19.2
unnamed: Q10.1 (C), x7.1 (K)
unnamed: Q11.2 (B), R21.2
unnamed: Q11.1 (C), x8.1 (K)
unnamed: Q12.2 (B), R23.2
unnamed: Q12.1 (C), x9.1 (K)
unnamed: R8.1, x1.2 (A)
unnamed: R10.1, x2.2 (A)
unnamed: R12.1, x3.2 (A)
unnamed: R14.1, x4.2 (A)
unnamed: R16.1, x5.2 (A)
unnamed: R18.1, x6.2 (A)
unnamed: R20.1, x7.2 (A)
unnamed: R22.1, x8.2 (A)
unnamed: R24.1, x9.2 (A)
x1: R7.1; also elsewhere on the board
x2: R9.1; also elsewhere on the board
x3: R11.1; also elsewhere on the board
x4: R13.1; also elsewhere on the board
x5: R15.1; also elsewhere on the board
x6: R17.1; also elsewhere on the board
x7: R19.1; also elsewhere on the board
x8: R21.1; also elsewhere on the board
x9: R23.1; also elsewhere on the board

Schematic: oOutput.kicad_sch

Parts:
Q13, Q14, Q15, Q16, Q17, Q18, Q19, Q20, Q21: NPN; TO-92_Inline
R25, R26, R27, R31, R32, R33, R37, R38, R39: 6800; R_Axial_DIN0309_L9.0mm_D3.2mm_P12.70mm_Horizontal
R28, R29, R30, R34, R35, R36, R40, R41, R42: 150; R_Axial_DIN0207_L6.3mm_D2.5mm_P7.62mm_Horizontal
o1, o2, o3, o4, o5, o6, o7, o8, o9: LED; LED_D3.0mm

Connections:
+5V: R28.2, R29.2, R30.2, R34.2, R35.2, R36.2, R40.2, R41.2, R42.2; also elsewhere on the board
GND: Q13.3 (E), Q14.3 (E), Q15.3 (E), Q16.3 (E), Q17.3 (E), Q18.3 (E), Q19.3 (E), Q20.3 (E), Q21.3 (E); also elsewhere on the board
unnamed: Q13.2 (B), R25.2
unnamed: Q13.1 (C), o7.1 (K)
unnamed: Q14.2 (B), R26.2
unnamed: Q14.1 (C), o4.1 (K)
unnamed: Q15.2 (B), R27.2
unnamed: Q15.1 (C), o1.1 (K)
unnamed: Q16.2 (B), R31.2
unnamed: Q16.1 (C), o8.1 (K)
unnamed: Q17.2 (B), R32.2
unnamed: Q17.1 (C), o5.1 (K)
unnamed: Q18.2 (B), R33.2
unnamed: Q18.1 (C), o2.1 (K)
unnamed: Q19.2 (B), R37.2
unnamed: Q19.1 (C), o9.1 (K)
unnamed: Q20.2 (B), R38.2
unnamed: Q20.1 (C), o6.1 (K)
unnamed: Q21.2 (B), R39.2
unnamed: Q21.1 (C), o3.1 (K)
unnamed: R30.1, o1.2 (A)
unnamed: R36.1, o2.2 (A)
unnamed: R42.1, o3.2 (A)
unnamed: R29.1, o4.2 (A)
unnamed: R35.1, o5.2 (A)
unnamed: R41.1, o6.2 (A)
unnamed: R28.1, o7.2 (A)
unnamed: R34.1, o8.2 (A)
unnamed: R40.1, o9.2 (A)
o1: R27.1; also elsewhere on the board
o2: R33.1; also elsewhere on the board
o3: R39.1; also elsewhere on the board
o4: R26.1; also elsewhere on the board
o5: R32.1; also elsewhere on the board
o6: R38.1; also elsewhere on the board
o7: R25.1; also elsewhere on the board
o8: R31.1; also elsewhere on the board
o9: R37.1; also elsewhere on the board

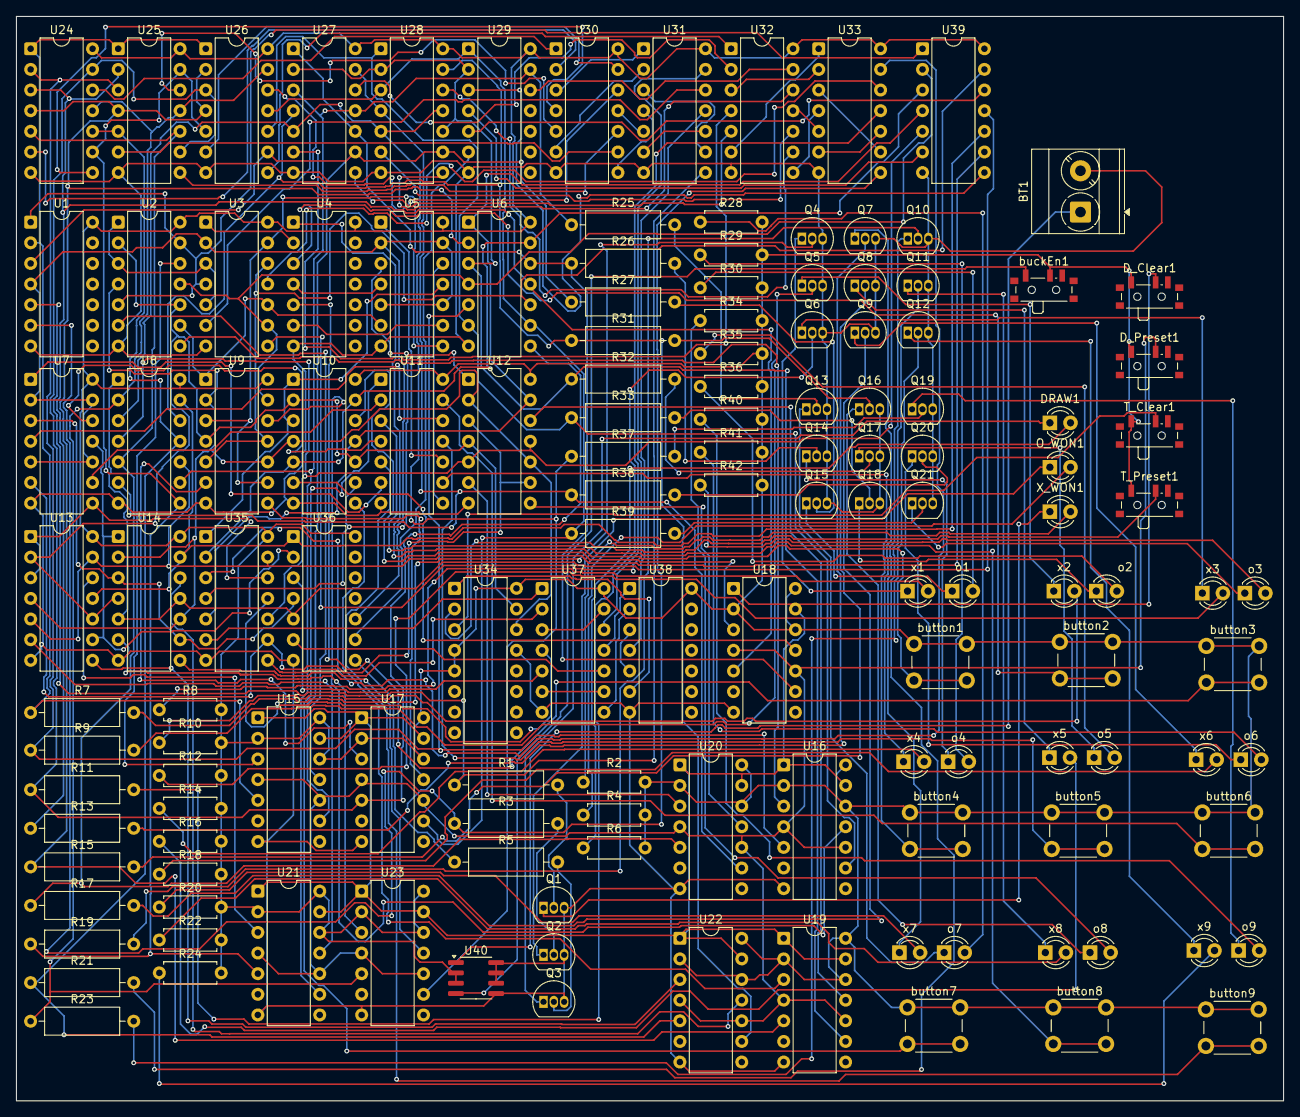
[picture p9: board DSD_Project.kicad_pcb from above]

Board: 2 copper layers, 156.0 x 133.5 mm, 139 parts (0 on the bottom side), 198 nets.
